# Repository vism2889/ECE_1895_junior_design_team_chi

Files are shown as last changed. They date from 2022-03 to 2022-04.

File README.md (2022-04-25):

# Junior Design Team Chi: Design Project # 2
University of Pittsburgh <br>
Swanson School of Engineering <br>
Spring 2022 <br>
### Collaborator contributions to Team-Chi's Group Junior Design Project

# Navigating Repository:
There are 3 workspace directories included.  This is where all the project files and code can be found.<br>
1. one for arduino files labeled `pitt-traditions-arduino-ws` 
    - directory for the application files: `pitt-traditions`
    - directory for component testbenches: `component_test_benches`
    - directory for spoken-command mp3 files: `command_audio_files`
    - directory that holds the code used to convert audio-samples into program memory: `Arduino MP3`
3. one for Altium files labeled `pitt-traditions-altium-ws`
4. one for Fusion360 files labeled `pitt-traditions-fusion360-ws`

# Important Resources
[Team Availability](https://www.when2meet.com/?14987485-l46cu)
<br>
[Trello Task Board](https://trello.com/b/Vlmt92qO/team-task-board)

## Contributing Members & Roles:

| Member | Role |
| --- | --- |
| David Cramer | Integration Lead / scrum co-lead  |
| Christopher Guiher | Hardware Lead  |
| Alexander Shuster  | Fabrication Lead  |
| Morgan Visnesky | Software Lead / scrum co-lead  |

# [Proposed Project Description](https://github.com/vism2889/ECE_1895_junior_design_team_chi/blob/base-arduino-functionality/Team%20CHI%20Design%20Proposal.pdf)

# Game Play Instructions:
Press the red button to start a game. 
Once a game has begun, you will be prompted with a task on the screen
- Light the Victory Lights: Shine a flashlight on the top of the Cathedral of Learning
- Rub the Panther's Nose: Rub the Panther's Nose back and forth
- Cheer Hail to Pitt: Yell into the microphone and show off your Pitt Pride.

If you choose the correct input, you will get a point.  If you choose the incorrect input or run out of time, the game ends. <br>
After 99 consecutive points are scored the user will have won the game, and the user will be prompted with a winning message.

# Citations & References:
## Arduino Citations
- [MP3 Example](https://www.youtube.com/watch?v=m1HEwgHSBrs&t=9s)
- [Random Reference](https://www.arduino.cc/en/Reference/Random)
- [I2C LCD Example #1](https://github.com/johnrickman/LiquidCrystal_I2C/blob/master/examples/HelloWorld/HelloWorld.pde)
- [I2C LCD Example #2](https://create.arduino.cc/projecthub/Arnov_Sharma_makes/lcd-i2c-tutorial-664e5a)
- [Mic Example](https://www.aranacorp.com/en/using-a-microphone-with-arduino/)
- [Text To Speech](https://ttsmp3.com/)
- [Updated Audio Converter](https://github.com/damellis/EncodeAudio/blob/36c9dcb94ca66bf2e319c84b3f95d38b755265b2/EncodeAudio.pde)
- [Sampling From Microphone](https://learn.adafruit.com/adafruit-microphone-amplifier-breakout/measuring-sound-levels)
## Altium Citations
- [Altium Tutorial](https://www.altium.com/documentation/altium-designer/tutorial-complete-design-walkthrough) 
## Fusion360 Citations
- TBD

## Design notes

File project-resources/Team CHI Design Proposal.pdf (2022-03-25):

ECE 1895 Junior Design
Spring 2022

TEAM CHI
Members:
David Cramer, Christopher Guiher, Alexander Shuster, Morgan Visnesky

TEAM ROLES:
David Cramer: Integration Lead / scrum co-lead
Christopher Guiher: Hardware Lead
Alexander Shuster: Fabrication Lead
Morgan Visnesky: Software Lead / scrum co-lead

Team CHI Project Proposal: Originally Conceptualized by Christopher Guiher PITT TRADITIONS

For the Team-Chi BOP-IT proposal, we have decided to elaborate on the initial proposal made by Christopher who centered their user inputs around some of their favorite Pitt traditions.

The design will be encased in a model Cathedral of Learning and Panther Statue. A power switch and a ‘Start Game’ button will be connected to the base of the model. The power supply for the toy will come from a 9V battery. Once the game is started, a speaker will be used to prompt the user via pre-recorded audio messages to carry out one of 3 actions: Light the Victory Lights, Rub Panther’s Nose, or shout Let’s Go Pitt.

Light the Victory Lights: This action will be accomplished by positioning a blue and yellow LED as ‘spotlights’ directed towards a photoresistor positioned atop the Cathedral of Learning model. The user will be able to press a push-button that will trigger the spotlight to shine towards the photoresistor. Alternately, the user will be provided with a small, blue, keychain flashlight that will be used to trigger the photoresistor. This will provide a digital input into the microcontroller that verifies if the user chose the correct action.

Rub the Panther’s Nose: This action will be accomplished by moving a joystick positioned on the panther’s nose. The joystick will only consist of a single axis. Inputs will be considered valid if the joystick makes multiple oscillations from left to right or right to left.

Let’s Go Pitt: A microphone will be positioned on the base of the model. To accomplish this action, the user should cheer into the microphone. The microcontroller will compare the ambient noise with the noise immediately after the prompt to detect if the correct input was provided.

Option #1:
The ‘Pitt Traditions’ Bop-It toy will give the user a set time interval to complete each task that will decrease linearly as an inverse function of the number of points the user has scored. Tasks will be chosen randomly, by using a disconnected analog pin as a seed reference and using the Arduino’s random function. If a task is completed successfully, an LED on the model’s base will light up. If an incorrect action is chosen, or the allotted time has run out, a different LED will notify the user that the game is over. Two 7-Segment displays will be used to provide the user their score. If the user produces 99 successful actions, a special audio will be played notifying the user that they have won the game.

Option #2:
The ‘Pitt Traditions’ Bop-It toy will give the user a set time interval to complete each task that will decrease linearly as an inverse function of the number of rounds the user has completed. A. round will be a grouping of 5 random tasks with an equal interval of time between each task. Tasks will be chosen randomly, by using a disconnected analog pin as a seed reference and using the Arduino’s random function. If a task is completed successfully, an LED on the model’s base will light up. If an incorrect action is chosen, or the allotted time has run out, a different LED will notify the user that the game is over. After 20 rounds (or 99/100 completed tasks) the game will conclude, and the user will have won. Two 7-Segment displays will be used to provide the user their score. If the user produces 99 successful actions, the “Hail to Pitt” jingle will play to let the user know they have beaten the game.

Block Diagram:

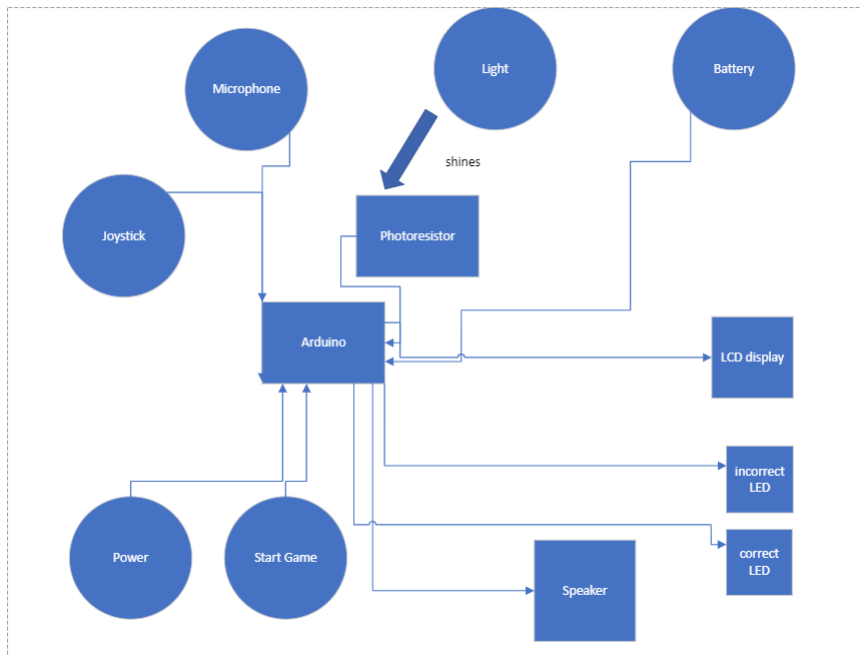
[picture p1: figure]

PSEUDO CODE:

// INPUTS
Const int micPin | = 13;
Const int joyStickPin | = 12;
Const int photoResistorPin = 2; Const int startButton = 8;

// OUTPUTS
Const int speakerPin = 4;
Const int hexDisplayPin = 7;

// VARIABLES
Int curr_time = 0;
Int command_count = 0;

Void setup()
{
// INPUTS
pinMode(micPin, INPUT);
pinMode(joyStickPin, INPUT); pinMode(lightDependentResistorPin, INPUT); pinMode(startButton, INPUT);

// OUTPUTS
pinMode(speakerPin, OUTPUT); pinMode(hexDisplayPin, OUTPUT);

Time = getCurrTime();
}

panthers_nose()
{
Time = currTime;
Command = rubNose;
Speak-command();
If (nose_joy_stick == moved and getTime() - Time < currTimeInterval) {
Score += 1;
}
Else
{
displayFinalScore();
game_started = false;
}
}

victory_lights()
{
Time = currTime;
Command = victoryLights;
Speak-command();
If (lightSensorPin == HIGH and getTime() - Time< currTimeInterval) {
Score += 1;
}

Else
{
displayFinalScore();
game_started = false;
}
}

hail_to_pitt()
{
Time = currTime;
Command = hailToPitt;
Speak-command();
If (microphonePin == HIGH and getTime() - Time < currTimeInterval) {
Score += 1;
}
Else
{
displayFinalScore();
game_started = false;
}
}

pickRamdomCommand()
{
Random_command = random(
hail_to_pitt(),
victory_lights(),
panthers_nose());
Command_count += 1;
Return random_command;
}

Void loop()
{
while(game_started == true) {
If (command_count <= 99)
{
playWinningJingle();
Game_started = false;
}
Command = pickRandomCommand(); }
}

Sketch of 3D Model / Project Enclosure:

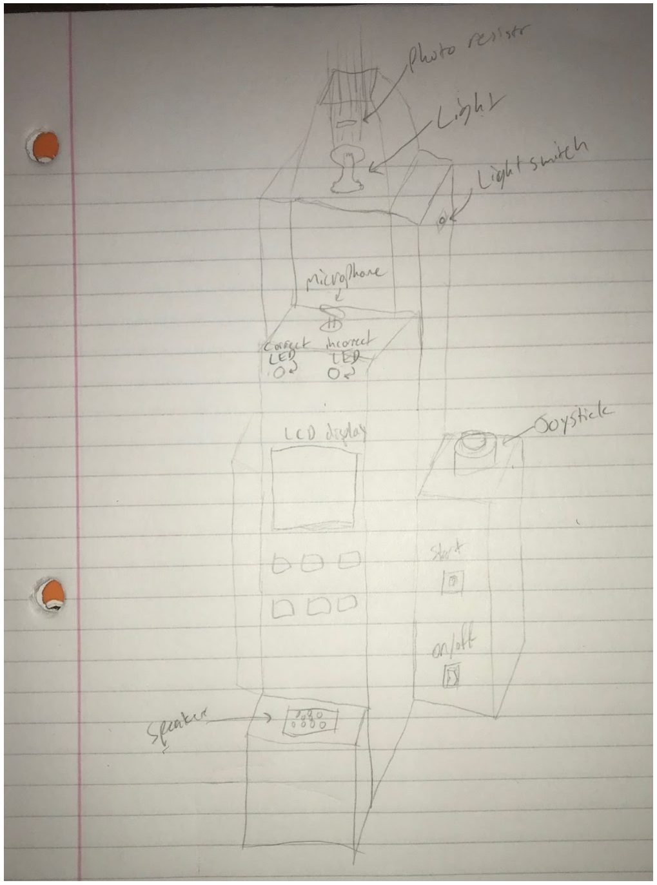
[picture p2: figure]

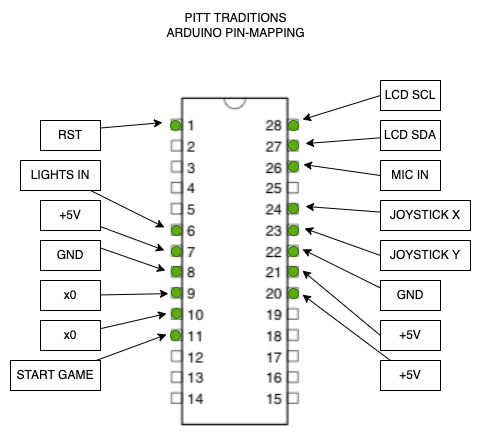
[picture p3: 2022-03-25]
project-resources/pin-mapping-PITT-TRADITIONS.png

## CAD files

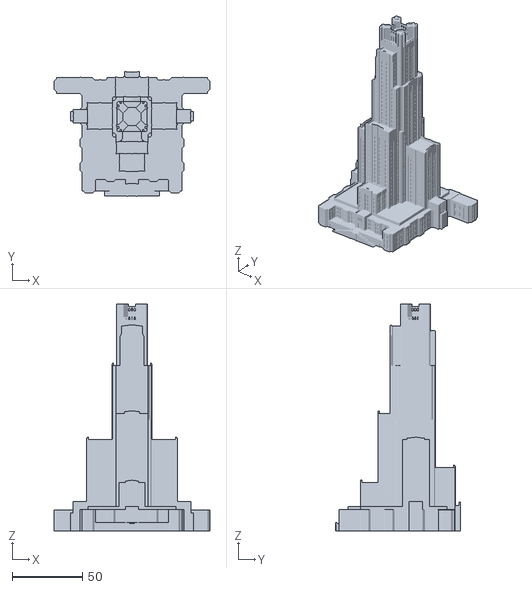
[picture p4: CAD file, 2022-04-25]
pitt-traditions-models-ws/CL_whole.stl
111.0 x 89.1 x 162.0

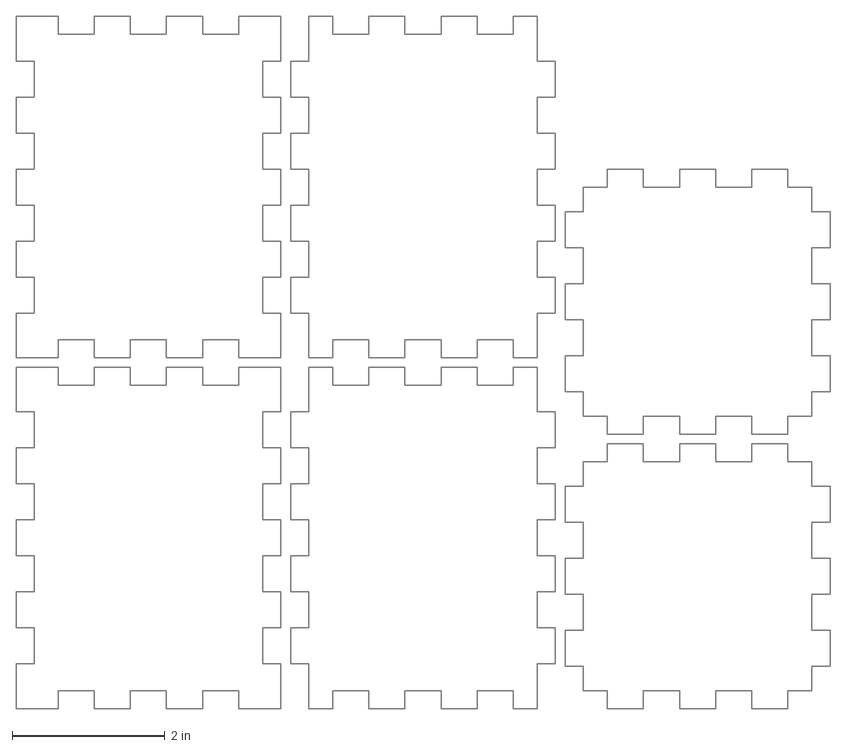
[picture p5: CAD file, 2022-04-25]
pitt-traditions-models-ws/box (1).dxf
10.7 x 9.07 in

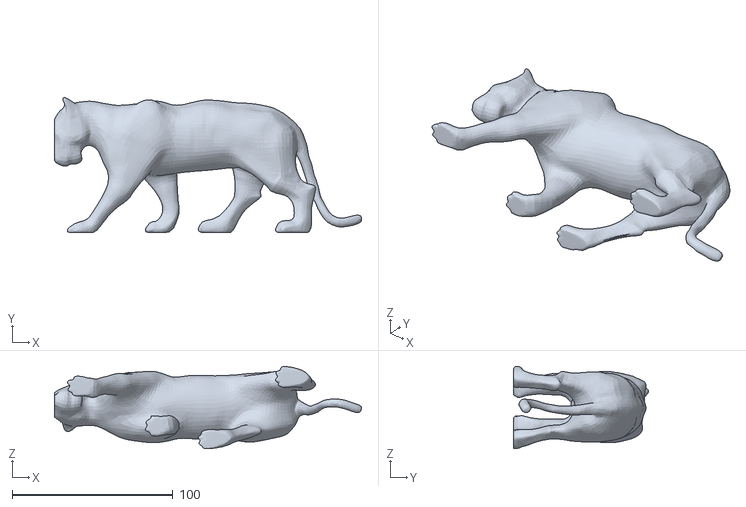
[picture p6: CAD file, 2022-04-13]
pitt-traditions-models-ws/Panther v3.stl
191.1 x 84.0 x 51.1

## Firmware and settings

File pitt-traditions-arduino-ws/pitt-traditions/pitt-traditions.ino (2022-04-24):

/**************************************************************
 * AUTHOR(S):    Morgan Visnesky and Chris Guiher
 * DATE:         03/18/2022
 * FILENAME:     pitt-traditions.ino
 * ORGANIZATION: Junior Design Team CHI
 * TEAM MEMBERS: 
 *              Chris Guiher 
 *              Alex Shuster
 *              Morgan Visnesky
 *              David Cramer
 *
 * DESCRIPTION: 
 *     Driver file for Pitt-Traditions "Bop-it" Arduino application.
 **************************************************************/

// IMPORTED CODE
#include <PCM.h>               // Library for MP3 playback
// #include <LiquidCrystal_I2C.h> // Library for I2C LCD display 
#include "pin-mapping.h"       // Project Pin-mapping Definitions
#include "game-samples.h"      // Project Audio Samples
#include "lcd_messages.h"      // Methods that hold LCD messages


char dtaUart[15];
char dtaLen = 0;
unsigned long currTime = 0;
int command_count = 0;
int userScore     = 0;
int randomNumber;
unsigned long timeInterval = 1000 * 4; // four second time interval to start 
boolean game_started = false; // value to indicate whether game is active or not

/*
 * Method to hold the base pinMappings to from the arduinos inputs and outputs
 * along with class 'state' variables.
 */
void setup()
{
  // Sets the random seed from noise when analog pin 0 is disconnected
  // Will generate a different seed number each time the application is run
  randomSeed(analogRead(randomPin)); 
  pinMode(micPin,                    INPUT);
  pinMode(joyStickPin,               INPUT);
  pinMode(photoResistorPin,          INPUT);
  pinMode(startSwitch,               INPUT);
  pinMode(speakerPin,                OUTPUT);
  Serial.begin(115200);
  lcd.init();
  welcomeMessage();
}

/*
 * Method to hold the functionality of the panthers_nose command-action.
 */
void panthers_nose()
{
  boolean completedTaskInTime = false;
  startPlayback(panthersNoseSample, sizeof(panthersNoseSample));
  panthersNoseMessage(); // Displays command on LCD
  currTime = abs(millis());
  while (abs(millis()) - currTime < timeInterval)
  {
    int joyStickState = analogRead(1);
    if (joyStickState <= 400 or joyStickState >= 620)
    {
      userScore += 1; 
      completedTaskInTime = true;
      roundSuccessMessage(userScore);
      delay(1000);
      break;
    }
  }
  if (!completedTaskInTime)
  {
    game_started = false;
    roundFailMessage(userScore);
    
  }
  timeInterval -= 20;
}

/*
 * Method to hold the functionality of the victory_lights command-action.
 */
void victory_lights()
{
  boolean completedTaskInTime = false;
  startPlayback(victoryLightsSample, sizeof(victoryLightsSample));
  delay(1000);
  lightVictoryLightMessage(); // Displays command on LCD
  currTime = abs(millis());
  while (abs(millis()) - currTime < timeInterval)
  {
    int photoTransState = digitalRead(2);
    if (photoTransState == HIGH)
    {
      userScore += 1; 
      completedTaskInTime = true;
      roundSuccessMessage(userScore);
      delay(1000);
      break;
    }
  }
  if (!completedTaskInTime)
  {
    game_started = false;
    roundFailMessage(userScore);
  }
  timeInterval -= 20;
}

/*
 * Method to hold the functionality of the hail_to_pitt command-action.
 */
void hail_to_pitt()
{
  boolean completedTaskInTime = false;
  startPlayback(hailToPittSample, sizeof(hailToPittSample));
  delay(1000);
  hailToPittMessage(); // Displays command on LCD
  currTime = abs(millis());
  while (abs(millis()) - currTime < timeInterval)
  {   
    if (readFromMicrophone())
    {
      userScore += 1; 
      completedTaskInTime = true;
      roundSuccessMessage(userScore);
      delay(1000);
      break;
    }
  }
  if (!completedTaskInTime)
  {
    game_started = false;
    roundFailMessage(userScore);
  }
  timeInterval -= 20;
}


/*
 * Method to hold functionality that chooses a command at random from a list of
 * predefined commands.
 */
int pickRandomCommand()
{
  int random_command = random(0,3);  
  command_count += 1;
  return random_command;
}

/*
 * Method to hold functionality that is executed when an application error is raised
 */
void raise_application_error()
{
  Serial.print("Application Error Encountered");
}

/*
 * Method to hold the functionality to read an analog value from the microphone
 */
boolean readFromMicrophone()
{
  unsigned long startMillis= abs(millis());  // Start of sample window
  const int sampleWindow = 50; // Sample window width in mS (50 mS = 20Hz)
  double micVal = 0;
  boolean cheer = false;
  startMillis= millis();  // Start of sample window
  unsigned int peakToPeak = 0;   // peak-to-peak level
  unsigned int signalMax = 0;
  unsigned int signalMin = 1024;
  while (abs(millis()) - startMillis < sampleWindow) // collect data for 50 mS
  {
    int sample = analogRead(0);
    if (sample < 1024)  // toss out spurious readings
    {
      if (sample > signalMax)
      {
        signalMax = sample;  // save just the max levels
      }
      else if (sample < signalMin)
      {
        signalMin = sample;  // save just the min levels
      }
    }
  }
  peakToPeak = signalMax - signalMin;  // max - min = peak-peak amplitude
  micVal = (peakToPeak * 5.0) / 1024;  // convert to volts 
  if (micVal > 2) 
  {
    cheer = true;
  }
  else 
  {
    cheer = false;
  }
  return cheer;
}

/*
 * Main application loop that holds the overarching logic flow for the pitt-traditions
 * Bop-It game.
 */
void loop()
{ 
  if(dtaLen == 11) { // Setups LCD for correct display settings
    int r = (dtaUart[0]-'0')*100 + (dtaUart[1] - '0')*10 + (dtaUart[2] - '0'); 
    int g = (dtaUart[4]-'0')*100 + (dtaUart[5] - '0')*10 + (dtaUart[6] - '0');
    int b = (dtaUart[8]-'0')*100 + (dtaUart[9] - '0')*10 + (dtaUart[10] - '0');
    dtaLen = 0;
    lcd.setRGB(r, g, b);
    lcd.stopBlink();
    lcd.noBlinkLED();
  }// END LCD display settings

  int startState = digitalRead(startSwitch);
  if (startState == LOW)
  {
    Serial.print("game started");
    game_started = true;
  }
  // else
  // {
  //   game_started = false;
  // }

  // GAME PLAY LOGIC FLOW
  while(game_started == true)
  {
    if (userScore >= 99)
    {
      gameWonMessage(userScore);
      game_started = false;
    }
    else
    {
      int issuedCommand = pickRandomCommand();
      switch(issuedCommand)
      {
        case 0:
          hail_to_pitt();
          break;
        case 1:
          victory_lights();
          break;
        case 2:
          panthers_nose();
          break;
        default:
          raise_application_error();
          break;
      } 
    }
  }
}

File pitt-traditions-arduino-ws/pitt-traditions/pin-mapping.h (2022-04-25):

/**************************************************************
 * AUTHOR(S):    Morgan Visnesky
 * DATE:         03/25/2022
 * FILENAME:     pin-mapping.h
 * ORGANIZATION: Junior Design Team CHI
 * TEAM MEMBERS: 
 *              Chris Guiher 
 *              Alex Shuster
 *              Morgan Visnesky
 *              David Cramer
 *
 * DESCRIPTION: 
 *     Holds game pin-mapping constants
 **************************************************************/

// INPUT VARIABLES THAT MAP TO ARDUINO PINS
const int micPin            = 17;
const int joyStickPin       = 12;
const int photoResistorPin  = 4;
const int startSwitch       = 6;

// OUTPUT VARIABLES THAT MAP TO ARDUINO PINS
const int speakerPin        = 11;
const int hexDisplayPin     = 7;

// 'RANDOM' VARIABLES THAT MAP TO ARDUINO PINS
const int randomPin         = 0;

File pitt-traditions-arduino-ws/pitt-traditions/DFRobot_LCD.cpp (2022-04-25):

/*!
 * @file DFRobot_LCD.cpp
 * @brief DFRobot's LCD
 * @n High Accuracy Ambient Light Sensor
 *
 * @copyright	[DFRobot](http://www.dfrobot.com), 2016
 * @copyright	GNU Lesser General Public License
 *
 * @author [yangyang](971326313@qq.com)
 * @version  V1.0
 * @date  2017-2-10
 */

#include <Arduino.h>
#include <stdio.h>
#include <string.h>
#include <inttypes.h>
#include <Wire.h>

#include "DFRobot_LCD.h"

const uint8_t color_define[4][3] = 
{
    {255, 255, 255},            // white
    {255, 0, 0},                // red
    {0, 255, 0},                // green
    {0, 0, 255},                // blue
};

/*******************************public*******************************/
DFRobot_LCD::DFRobot_LCD(uint8_t lcd_cols,uint8_t lcd_rows,uint8_t lcd_Addr,uint8_t RGB_Addr)
{
  _lcdAddr = lcd_Addr;
  _RGBAddr = RGB_Addr;
  _cols = lcd_cols;
  _rows = lcd_rows;
}

void DFRobot_LCD::init()
{
	Wire.begin();
	_showfunction = LCD_4BITMODE | LCD_1LINE | LCD_5x8DOTS;
	begin(_cols, _rows);
}

void DFRobot_LCD::clear()
{
    command(LCD_CLEARDISPLAY);        // clear display, set cursor position to zero
    delayMicroseconds(2000);          // this command takes a long time!
}

void DFRobot_LCD::home()
{
    command(LCD_RETURNHOME);        // set cursor position to zero
    delayMicroseconds(2000);        // this command takes a long time!
}

void DFRobot_LCD::noDisplay()
{
    _showcontrol &= ~LCD_DISPLAYON;
    command(LCD_DISPLAYCONTROL | _showcontrol);
}

void DFRobot_LCD::display() {
    _showcontrol |= LCD_DISPLAYON;
    command(LCD_DISPLAYCONTROL | _showcontrol);
}

void DFRobot_LCD::stopBlink()
{
    _showcontrol &= ~LCD_BLINKON;
    command(LCD_DISPLAYCONTROL | _showcontrol);
}
void DFRobot_LCD::blink()
{
    _showcontrol |= LCD_BLINKON;
    command(LCD_DISPLAYCONTROL | _showcontrol);
}

void DFRobot_LCD::noCursor()
{
    _showcontrol &= ~LCD_CURSORON;
    command(LCD_DISPLAYCONTROL | _showcontrol);
}

void DFRobot_LCD::cursor() {
    _showcontrol |= LCD_CURSORON;
    command(LCD_DISPLAYCONTROL | _showcontrol);
}

void DFRobot_LCD::scrollDisplayLeft(void)
{
    command(LCD_CURSORSHIFT | LCD_DISPLAYMOVE | LCD_MOVELEFT);
}

void DFRobot_LCD::scrollDisplayRight(void)
{
    command(LCD_CURSORSHIFT | LCD_DISPLAYMOVE | LCD_MOVERIGHT);
}

void DFRobot_LCD::leftToRight(void)
{
    _showmode |= LCD_ENTRYLEFT;
    command(LCD_ENTRYMODESET | _showmode);
}

void DFRobot_LCD::rightToLeft(void)
{
    _showmode &= ~LCD_ENTRYLEFT;
    command(LCD_ENTRYMODESET | _showmode);
}

void DFRobot_LCD::noAutoscroll(void)
{
    _showmode &= ~LCD_ENTRYSHIFTINCREMENT;
    command(LCD_ENTRYMODESET | _showmode);
}

void DFRobot_LCD::autoscroll(void)
{
    _showmode |= LCD_ENTRYSHIFTINCREMENT;
    command(LCD_ENTRYMODESET | _showmode);
}

void DFRobot_LCD::customSymbol(uint8_t location, uint8_t charmap[])
{

    location &= 0x7; // we only have 8 locations 0-7
    command(LCD_SETCGRAMADDR | (location << 3));
    
    
    uint8_t data[9];
    data[0] = 0x40;
    for(int i=0; i<8; i++)
    {
        data[i+1] = charmap[i];
    }
    send(data, 9);
}

void DFRobot_LCD::setCursor(uint8_t col, uint8_t row)
{

    col = (row == 0 ? col|0x80 : col|0xc0);
    uint8_t data[3] = {0x80, col};

    send(data, 2);

}

void DFRobot_LCD::setRGB(uint8_t r, uint8_t g, uint8_t b)
{
    setReg(REG_RED, r);
    setReg(REG_GREEN, g);
    setReg(REG_BLUE, b);
}


void DFRobot_LCD::setColor(uint8_t color)
{
    if(color > 3)return ;
    setRGB(color_define[color][0], color_define[color][1], color_define[color][2]);
}

void DFRobot_LCD::blinkLED(void)
{
    ///< blink period in seconds = (<reg 7> + 1) / 24
    ///< on/off ratio = <reg 6> / 256
    setReg(0x07, 0x17);  // blink every second
    setReg(0x06, 0x7f);  // half on, half off
}

void DFRobot_LCD::noBlinkLED(void)
{
    setReg(0x07, 0x00);
    setReg(0x06, 0xff);
}

inline size_t DFRobot_LCD::write(uint8_t value)
{

    uint8_t data[3] = {0x40, value};
    send(data, 2);
    return 1; // assume sucess
}

inline void DFRobot_LCD::command(uint8_t value)
{
    uint8_t data[3] = {0x80, value};
    send(data, 2);
}

void DFRobot_LCD::blink_on(){
	blink();
}

void DFRobot_LCD::blink_off(){
	stopBlink();
}

void DFRobot_LCD::cursor_on(){
	cursor();
}

void DFRobot_LCD::cursor_off(){
	noCursor();
}

void DFRobot_LCD::setBacklight(uint8_t new_val){
	if(new_val){
		blinkLED();		// turn backlight on
	}else{
		noBlinkLED();		// turn backlight off
	}
}

void DFRobot_LCD::load_custom_character(uint8_t char_num, uint8_t *rows){
		customSymbol(char_num, rows);
}

void DFRobot_LCD::printstr(const char c[]){
	///< This function is not identical to the function used for "real" I2C displays
	///< it's here so the user sketch doesn't have to be changed 
	print(c);
}

/*******************************private*******************************/
void DFRobot_LCD::begin(uint8_t cols, uint8_t lines, uint8_t dotsize) 
{
    if (lines > 1) {
        _showfunction |= LCD_2LINE;
    }
    _numlines = lines;
    _currline = 0;

    ///< for some 1 line displays you can select a 10 pixel high font
    if ((dotsize != 0) && (lines == 1)) {
        _showfunction |= LCD_5x10DOTS;
    }

    ///< SEE PAGE 45/46 FOR INITIALIZATION SPECIFICATION!
    ///< according to datasheet, we need at least 40ms after power rises above 2.7V
    ///< before sending commands. Arduino can turn on way befer 4.5V so we'll wait 50
    delay(50);


    ///< this is according to the hitachi HD44780 datasheet
    ///< page 45 figure 23

    ///< Send function set command sequence
    command(LCD_FUNCTIONSET | _showfunction);
    delay(5);  // wait more than 4.1ms
	
	///< second try
    command(LCD_FUNCTIONSET | _showfunction);
    delay(5);

    ///< third go
    command(LCD_FUNCTIONSET | _showfunction);




    ///< turn the display on with no cursor or blinking default
    _showcontrol = LCD_DISPLAYON | LCD_CURSOROFF | LCD_BLINKOFF;
    display();

    ///< clear it off
    clear();

    ///< Initialize to default text direction (for romance languages)
    _showmode = LCD_ENTRYLEFT | LCD_ENTRYSHIFTDECREMENT;
    ///< set the entry mode
    command(LCD_ENTRYMODESET | _showmode);
    
    
    ///< backlight init
    setReg(REG_MODE1, 0);
    ///< set LEDs controllable by both PWM and GRPPWM registers
    setReg(REG_OUTPUT, 0xFF);
    ///< set MODE2 values
    ///< 0010 0000 -> 0x20  (DMBLNK to 1, ie blinky mode)
    setReg(REG_MODE2, 0x20);
    
    setColorWhite();

}

void DFRobot_LCD::send(uint8_t *data, uint8_t len)
{
    Wire.beginTransmission(_lcdAddr);        // transmit to device #4
    for(int i=0; i<len; i++) {
        Wire.write(data[i]);
		delay(5);
    }
    Wire.endTransmission();                     // stop transmitting
}

void DFRobot_LCD::setReg(uint8_t addr, uint8_t data)
{
    Wire.beginTransmission(_RGBAddr); // transmit to device #4
    Wire.write(addr);
    Wire.write(data);
    Wire.endTransmission();    // stop transmitting
}
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

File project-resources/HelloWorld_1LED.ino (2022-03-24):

#define LED1 7
#define IN 4
// Chris Guiher 
// Alex Shuster
// Morgan Visnesky
// David Cramer

void setup() {
  // initialize digital pin LED_BUILTIN as an output.
  pinMode(LED1, OUTPUT);
  pinMode(IN,INPUT);
}

// the loop function runs over and over again forever
void loop() 
{
 digitalWrite(LED1, LOW);    // turn the LED off by making the voltage LOW
 if(digitalRead(IN)==LOW)
 {
    digitalWrite(LED1, HIGH);   // turn the LED on (HIGH is the voltage level)
    delay(1000);                       // wait for a second
    // wait for a second
    digitalWrite(LED1, LOW);    // turn the LED off by making the voltage LOW
    delay(1000); 
 }
 digitalWrite(LED1,LOW);
}

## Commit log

2022-03-18 initialized arduino project files with slightly updated pseudo code
2022-03-22 Hello World Arduino Code
2022-03-24 Add files via upload
    Stl and obj files for enclosure model. CL-1-4 are different parts of cathedral model. We could possibly print these separately and put different PCBs in different sections for different inputs.
    [CL-1.stl, CL-2.stl, CL-3.stl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]
2022-03-24 updating to arduino code from psuedo code
2022-03-25 added arduino MP3 library and tool to convert MP3s to array, updated readme, added proposal PDF to repo
2022-03-25 updated citations in readme, added base I2C LCD functionality
2022-03-25 added diagram of current pin-mapping, small readme updates
2022-03-31 Add files via upload
    Updated Microphone read function to interprete peak-to-peak voltage
2022-03-31 cleaning up branch
    [CL-1.stl, CL-2.stl, CL-3.stl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]
2022-04-12 adding correct message functionality
    [lcd_test.ino]
2022-04-13 All Models
    Scaled Panther and Cathedral models and Ultimaker Cura file. Cathedral is split into 4 parts.
    [CL-1 v1.stl, CL-2 v1.stl, CL-3 v1.stl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]
2022-04-14 wrapping up application functionality, eliminating all error messages, beginning final tests
    [DFRobot_LCD.cpp, pin-mapping.h, pitt-traditions.ino]
2022-04-19 Update pitt-traditions.ino
    correcting negative millis error
    [pitt-traditions.ino]
2022-04-25 Add files via upload
    Updated files
    [box (1).dxf]
